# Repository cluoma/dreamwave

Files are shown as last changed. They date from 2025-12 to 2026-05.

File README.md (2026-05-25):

# Dreamwave - Wireless Dreamcast Controller

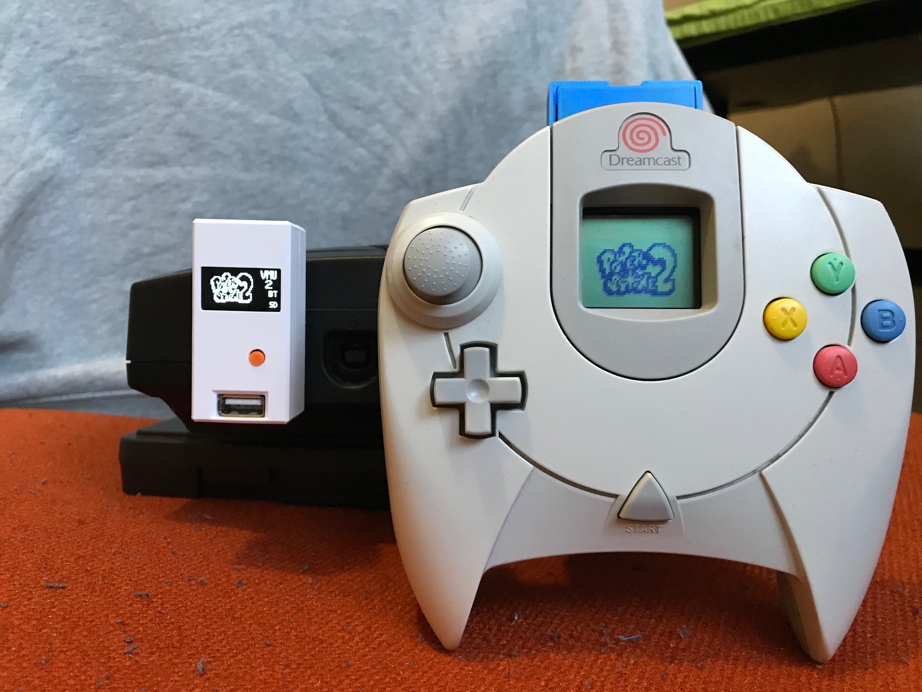
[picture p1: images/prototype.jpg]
Prototype


Dreamwave turns any OEM Dreamcast controller into a wireless Bluetooth gamepad.

Built using a Raspberry Pi Pico 2 W, it can be used both on a Dreamcast console (with additional hardware) or on a PC.

*The project is currently a proof-of-concept, integrating minimally with [Pico2Maple](https://github.com/cluoma/pico2maple-fw) for use on Dreamcast, and on PC with the help of Steam Input.*

# What Works

* **PC**: controller input only
* **Dreamcast** (with [Pico2Maple](https://github.com/cluoma/pico2maple-fw)): controller input and VMU LCD display in slot 1

# How It Works

Dreamwave uses the RP2350's PIO to emulate the Dreamcast's Maple bus. It queries the controller for its current input state and sends this over Bluetooth HID to a host device.

For the VMU display, Dreamwave accepts requests to open a custom Bluetooth Classic L2CAP channel for data exchange between the controller and host.

# Pairing

On boot, Dreamwave will always try and reconnect to the last-connected host. If this fails, it will fallback into pairing mode after about a minute.

# Hardware

All one needs hardware-wise is a Pico 2 W, a battery, and some charging/power circuitry. Then it is just a matter of finding a way to attach everything to the Dreamcast controller.

I wanted a big battery and did not want to modify the controller too much. So, I settled on the following components stuffed into a small case that lives in the second controller slot:

* Raspberry Pi Pico 2 W
* 1500mAh LiPo battery ([link](https://www.amazon.ca/dp/B07TXHWBSM))
* Pimoroni LiPo Shim ([link](https://shop.pimoroni.com/products/pico-lipo-shim?variant=32369543086163))
* 3.3 to 5v boost converter ([link](https://www.amazon.ca/dp/B0CRSW6ZTW))
* Female JST 2.0mm connector ([link](https://www.amazon.ca/Female-Connector-Strips-Household-Appliances/dp/B0F36P74QX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))

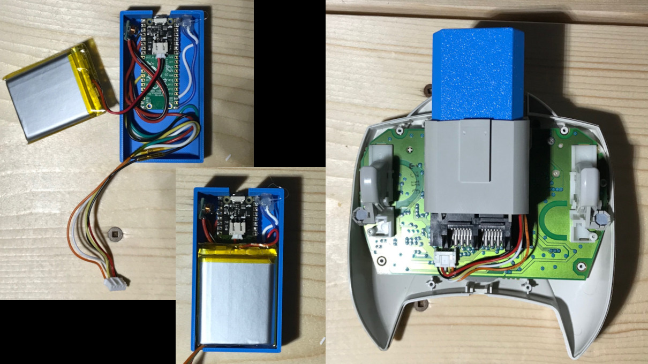
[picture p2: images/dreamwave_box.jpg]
Prototype Case


## Wiring

| Dreamcast Controller Pins (Left to Right) | |
|---|---|
| 1 | RP2350 Pin 21 (GPIO 16) |
| 2 | 5v |
| 3 | GND |
| 4 | GND |
| 5 | RP2350 Pin 22 (GPIO 17) |

Everything gets wired to the female JST header which can plug directly into the Dreamcast controller's PCB when wired the following way:

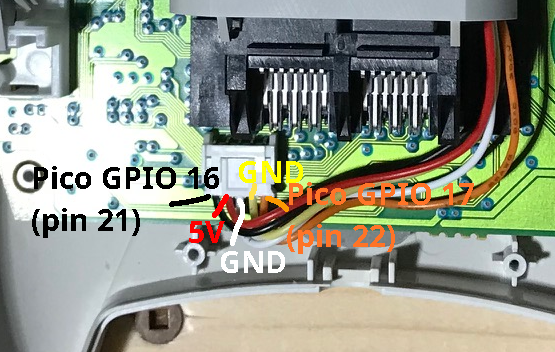
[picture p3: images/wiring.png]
Wiring


## Power Usage

The measured current draw from my battery is around 125mA without a VMU and around 160mA with a VMU. Keep this in mind when choosing the capacity of your battery.

# Libraries

* [pico-sdk](https://github.com/raspberrypi/pico-sdk) - [BSD 3-Clause](https://github.com/raspberrypi/pico-sdk/blob/master/LICENSE.TXT)
* [btstack](https://github.com/bluekitchen/btstack) - [non-commercial](https://github.com/bluekitchen/btstack/blob/master/LICENSE), [pico commercial exception](https://github.com/raspberrypi/pico-sdk/blob/master/src/rp2_common/pico_btstack/LICENSE.RP)
* [cyw43-driver](https://github.com/georgerobotics/cyw43-driver) - [License](https://github.com/georgerobotics/cyw43-driver/blob/main/LICENSE.RP)

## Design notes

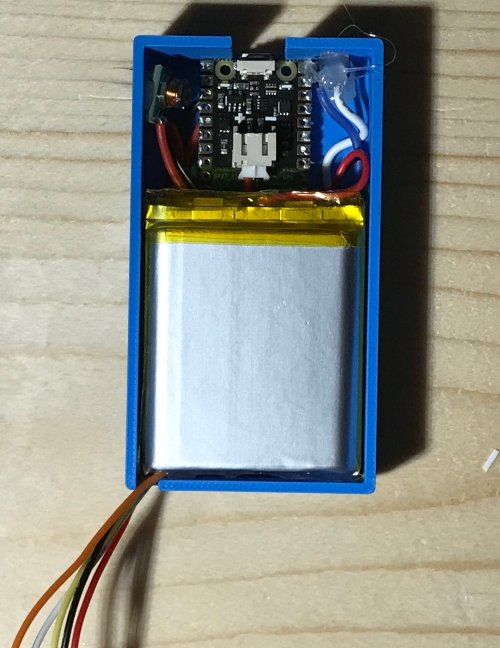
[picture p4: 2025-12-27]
images/prototype_case.png

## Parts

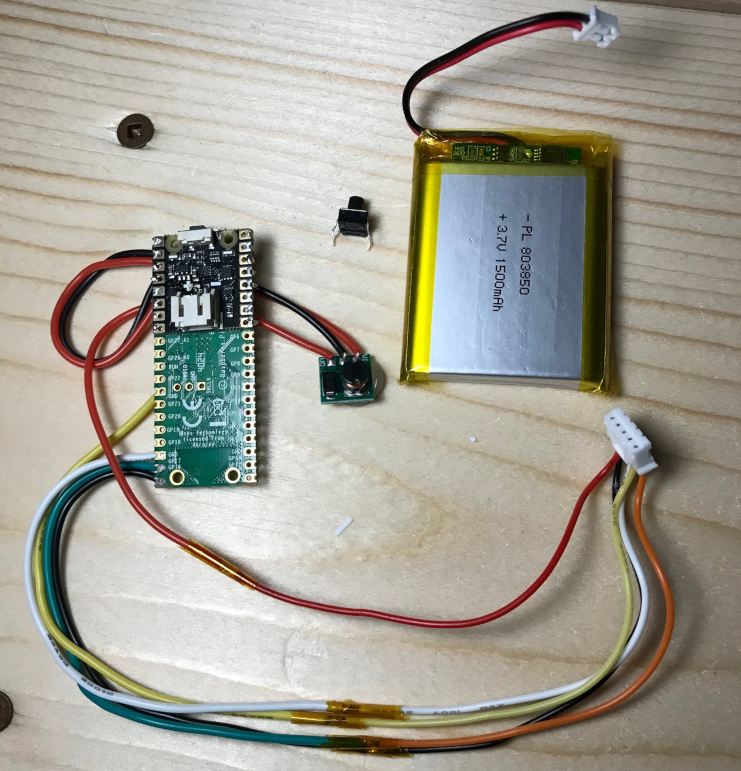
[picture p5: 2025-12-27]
images/components.png

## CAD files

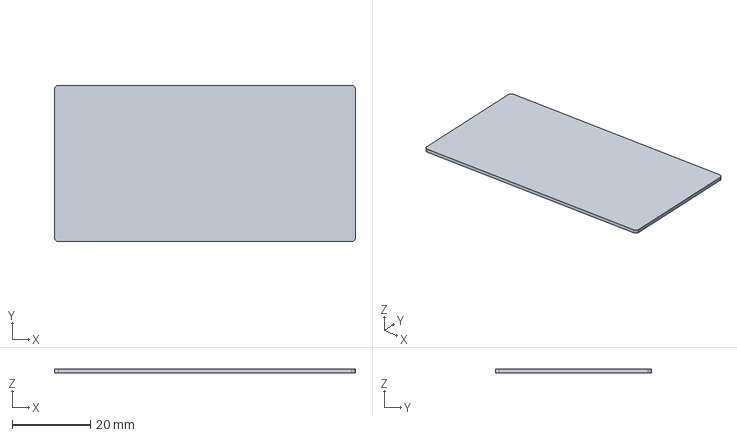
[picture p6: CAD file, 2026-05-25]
hardware/models/dreamwave_box_cover.FCStd
77.0 x 40.0 x 1.00 mm

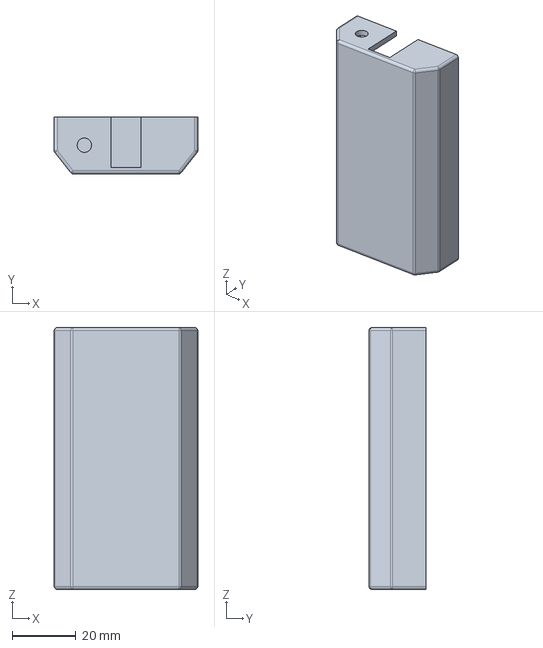
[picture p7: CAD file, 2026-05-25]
hardware/models/dreamwave_box.FCStd
45.0 x 17.8 x 82.0 mm

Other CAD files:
hardware/models/dreamwave_box.stl
hardware/models/dreamwave_box_cover.stl

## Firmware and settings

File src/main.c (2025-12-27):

/**
 * main.c
 *
 * Dreamwave setup and init
 *
 * Copyright (c) 2024 Colin Luoma
 */

#include <stdio.h>
#include <pico.h>
#include <stdlib.h>
#include <pico/cyw43_arch.h>
#include <pico/async_context_poll.h>
#include <pico/flash.h>
#include <pico/multicore.h>
#include <pico/stdio.h>

#include "maple.h"
#include "dw_bt_hid.h"

mp_dreamcast_t * mpb;
volatile bool core1_ready = false;

void maple_entry()
{
    // Enable core0 to lockout core1 while writing to flash
    flash_safe_execute_core_init();
    core1_ready = true;

    // Start Maple
    mp_dreamcast_init(mpb);
    mp_dreamcast_run(mpb);
}

int main(void)
{
    stdio_init_all();
    printf("Starting Dreamwave. It's thinking.\r\n");

    // Start maple on core1 right away
    mpb = malloc(sizeof(mp_dreamcast_t));
    multicore_reset_core1();
    multicore_launch_core1(maple_entry);
    while (!core1_ready) tight_loop_contents();

    // Setup our context to use with btstack
    async_context_poll_t bt_context;
    async_context_poll_init_with_defaults(&bt_context);
    cyw43_arch_set_async_context(&bt_context.core);

    while (cyw43_arch_init() != 0) {
        printf("failed to initialise cyw43_arch\r\n");
        sleep_ms(100);
    }

    while(mpb->state == MP_DREAMCAST_STATE_INITIALIZING) tight_loop_contents();

    // Run BTStack on core0
    dw_bt_init();

    while(true)
    {
        // Continuously poll for work
        async_context_poll(&bt_context.core);
    }
}

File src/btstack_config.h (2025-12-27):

#ifndef _PICO_BTSTACK_BTSTACK_CONFIG_H
#define _PICO_BTSTACK_BTSTACK_CONFIG_H

// BTstack features that can be enabled
#define ENABLE_LOG_INFO
#define ENABLE_LOG_ERROR
#define ENABLE_PRINTF_HEXDUMP
#define ENABLE_SCO_OVER_HCI

#ifdef ENABLE_BLE
#define ENABLE_GATT_CLIENT_PAIRING
#define ENABLE_L2CAP_LE_CREDIT_BASED_FLOW_CONTROL_MODE
#define ENABLE_LE_CENTRAL
#define ENABLE_LE_DATA_LENGTH_EXTENSION
#define ENABLE_LE_PERIPHERAL
#define ENABLE_LE_PRIVACY_ADDRESS_RESOLUTION
#define ENABLE_LE_SECURE_CONNECTIONS
#endif

#ifdef ENABLE_CLASSIC
#define ENABLE_L2CAP_ENHANCED_RETRANSMISSION_MODE
#define ENABLE_GOEP_L2CAP
#endif

#if defined (ENABLE_CLASSIC) && defined(ENABLE_BLE)
#define ENABLE_CROSS_TRANSPORT_KEY_DERIVATION
#endif

// BTstack configuration. buffers, sizes, ...
#define HCI_OUTGOING_PRE_BUFFER_SIZE 4
#define HCI_ACL_PAYLOAD_SIZE (1691 + 4)
#define HCI_ACL_CHUNK_SIZE_ALIGNMENT 4
#define MAX_NR_AVDTP_CONNECTIONS 1
#define MAX_NR_AVDTP_STREAM_ENDPOINTS 1
#define MAX_NR_AVRCP_CONNECTIONS 2
#define MAX_NR_BNEP_CHANNELS 1
#define MAX_NR_BNEP_SERVICES 1
#define MAX_NR_BTSTACK_LINK_KEY_DB_MEMORY_ENTRIES  2
#define MAX_NR_GATT_CLIENTS 1
#define MAX_NR_HCI_CONNECTIONS 2
#define MAX_NR_HID_HOST_CONNECTIONS 1
#define MAX_NR_HIDS_CLIENTS 1
#define MAX_NR_HFP_CONNECTIONS 1
#define MAX_NR_L2CAP_CHANNELS  6
#define MAX_NR_L2CAP_SERVICES  5
#define MAX_NR_RFCOMM_CHANNELS 1
#define MAX_NR_RFCOMM_MULTIPLEXERS 1
#define MAX_NR_RFCOMM_SERVICES 1
#define MAX_NR_SERVICE_RECORD_ITEMS 4
#define MAX_NR_SM_LOOKUP_ENTRIES 3
#define MAX_NR_WHITELIST_ENTRIES 16
#define MAX_NR_LE_DEVICE_DB_ENTRIES 16

// Limit number of ACL/SCO Buffer to use by stack to avoid cyw43 shared bus overrun
#define MAX_NR_CONTROLLER_ACL_BUFFERS 4
#define MAX_NR_CONTROLLER_SCO_PACKETS 4

// Enable and configure HCI Controller to Host Flow Control to avoid cyw43 shared bus overrun
#define ENABLE_HCI_CONTROLLER_TO_HOST_FLOW_CONTROL
#define HCI_HOST_ACL_PACKET_LEN 1024
#define HCI_HOST_ACL_PACKET_NUM 3
#define HCI_HOST_SCO_PACKET_LEN 120
#define HCI_HOST_SCO_PACKET_NUM 3

// Link Key DB and LE Device DB using TLV on top of Flash Sector interface
#define NVM_NUM_DEVICE_DB_ENTRIES 16
#define NVM_NUM_LINK_KEYS 16

// We don't give btstack a malloc, so use a fixed-size ATT DB.
#define MAX_ATT_DB_SIZE 512

// BTstack HAL configuration
#define HAVE_EMBEDDED_TIME_MS

// map btstack_assert onto Pico SDK assert()
#define HAVE_ASSERT

// Some USB dongles take longer to respond to HCI reset (e.g. BCM20702A).
#define HCI_RESET_RESEND_TIMEOUT_MS 1000

#define ENABLE_SOFTWARE_AES128
#define ENABLE_MICRO_ECC_FOR_LE_SECURE_CONNECTIONS

#define HAVE_BTSTACK_STDIN

// To get the audio demos working even with HCI dump at 115200, this truncates long ACL packets
//#define HCI_DUMP_STDOUT_MAX_SIZE_ACL 100

#endif // _PICO_BTSTACK_BTSTACK_CONFIG_H

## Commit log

2026-01-01 Add power usage info to readme and a different picture
2026-05-25 Add 3d models
    [dreamwave_box.FCStd, dreamwave_box.stl, dreamwave_box_cover.FCStd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]
